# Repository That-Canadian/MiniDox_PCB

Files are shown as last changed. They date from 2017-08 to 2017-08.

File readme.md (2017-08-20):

MiniDox PCB
===

MiniDox

These are the KiCad PCB source files for the MiniDox keyboard, created by u/That-Canadian on reddit

For the KiCad footprints/schematic libraries used please go to my [KiCad Library repo](https://github.com/That-Canadian/KiCad_Libs)

For case files / drawings see [DotDash32's Github](https://github.com/dotdash32/Cases/tree/master/Minidox)

For firmware files see the [QMK Github](https://github.com/qmk/qmk_firmware)

Copyright © 2017 Chirstopher Poole <maple-computing@vault-tech.net>
This work is free. You can redistribute it and/or modify it under the
terms of the Do What The Fuck You Want To Public License, Version 2,
as published by Sam Hocevar. See the LICENSE file for more details.

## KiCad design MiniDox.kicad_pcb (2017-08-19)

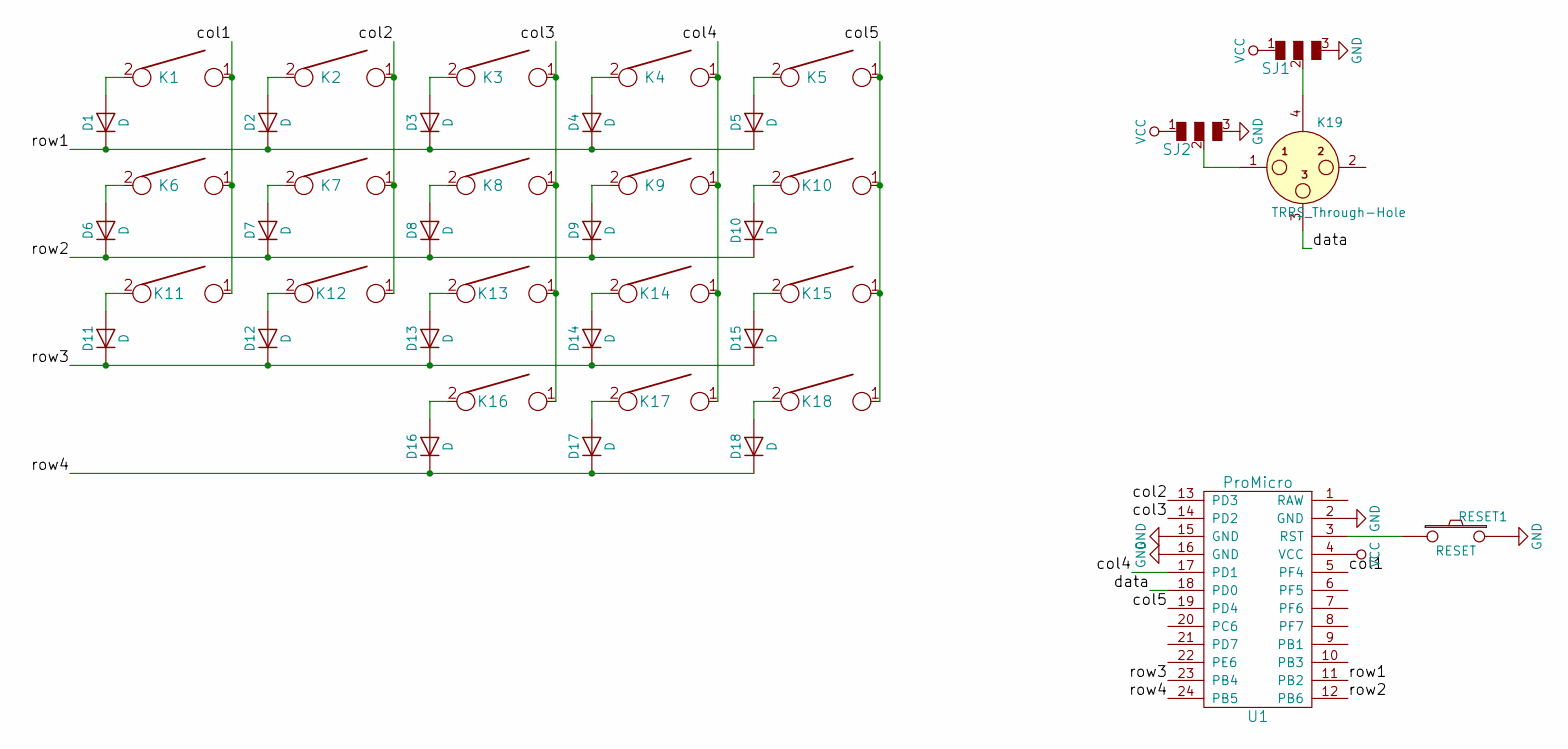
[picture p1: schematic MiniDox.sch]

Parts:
D1, D2, D3, D4, D5, D6, D7, D8, D9, D10, D11, D12, D13, D14, D15, D16, D17, D18: D; D_SOD123_axial-dual
K1, K2, K3, K4, K5, K6, K7, K8, K9, K10, K11, K12, K13, K14, K15, K16, K17: KEYSW; Mx_Alps_100-dualside
K18: KEYSW; Mx_Alps_175-dualside
K19: TRRS_Through-Hole; 4pin35mmAudio-dualsided
RESET1: RESET; SW_SPST_TL3342
SJ1, SJ2: SOLDER_JUMPER_3
U1: ProMicro; Pro_Micro

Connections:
/col1: K1.1, K6.1, K11.1, U1.5 (PF4)
/col2: K2.1, K7.1, K12.1, U1.13 (PD3)
/col3: K3.1, K8.1, K13.1, K16.1, U1.14 (PD2)
/col4: K4.1, K9.1, K14.1, K17.1, U1.17 (PD1)
/col5: K5.1, K10.1, K15.1, K18.1, U1.19 (PD4)
/data: K19.3, U1.18 (PD0)
/row1: D1.1 (K), D2.1 (K), D3.1 (K), D4.1 (K), D5.1 (K), U1.11 (PB2)
/row2: D6.1 (K), D7.1 (K), D8.1 (K), D9.1 (K), D10.1 (K), U1.12 (PB6)
/row3: D11.1 (K), D12.1 (K), D13.1 (K), D14.1 (K), D15.1 (K), U1.23 (PB4)
/row4: D16.1 (K), D17.1 (K), D18.1 (K), U1.24 (PB5)
GND: RESET1.2, SJ1.3, SJ2.3, U1.2 (GND), U1.15 (GND), U1.16 (GND); also elsewhere on the board
unnamed: D1.2 (A), K1.2
unnamed: D2.2 (A), K2.2
unnamed: D3.2 (A), K3.2
unnamed: D4.2 (A), K4.2
unnamed: D5.2 (A), K5.2
unnamed: D6.2 (A), K6.2
unnamed: D7.2 (A), K7.2
unnamed: D8.2 (A), K8.2
unnamed: D9.2 (A), K9.2
unnamed: D10.2 (A), K10.2
unnamed: D11.2 (A), K11.2
unnamed: D12.2 (A), K12.2
unnamed: D13.2 (A), K13.2
unnamed: D14.2 (A), K14.2
unnamed: D15.2 (A), K15.2
unnamed: D16.2 (A), K16.2
unnamed: D17.2 (A), K17.2
unnamed: D18.2 (A), K18.2
unnamed: K19.1, SJ2.2
unnamed: K19.4, SJ1.2
unnamed 32: RESET1.1, U1.3 (RST); also elsewhere on the board
VCC: SJ1.1, SJ2.1, U1.4 (VCC)

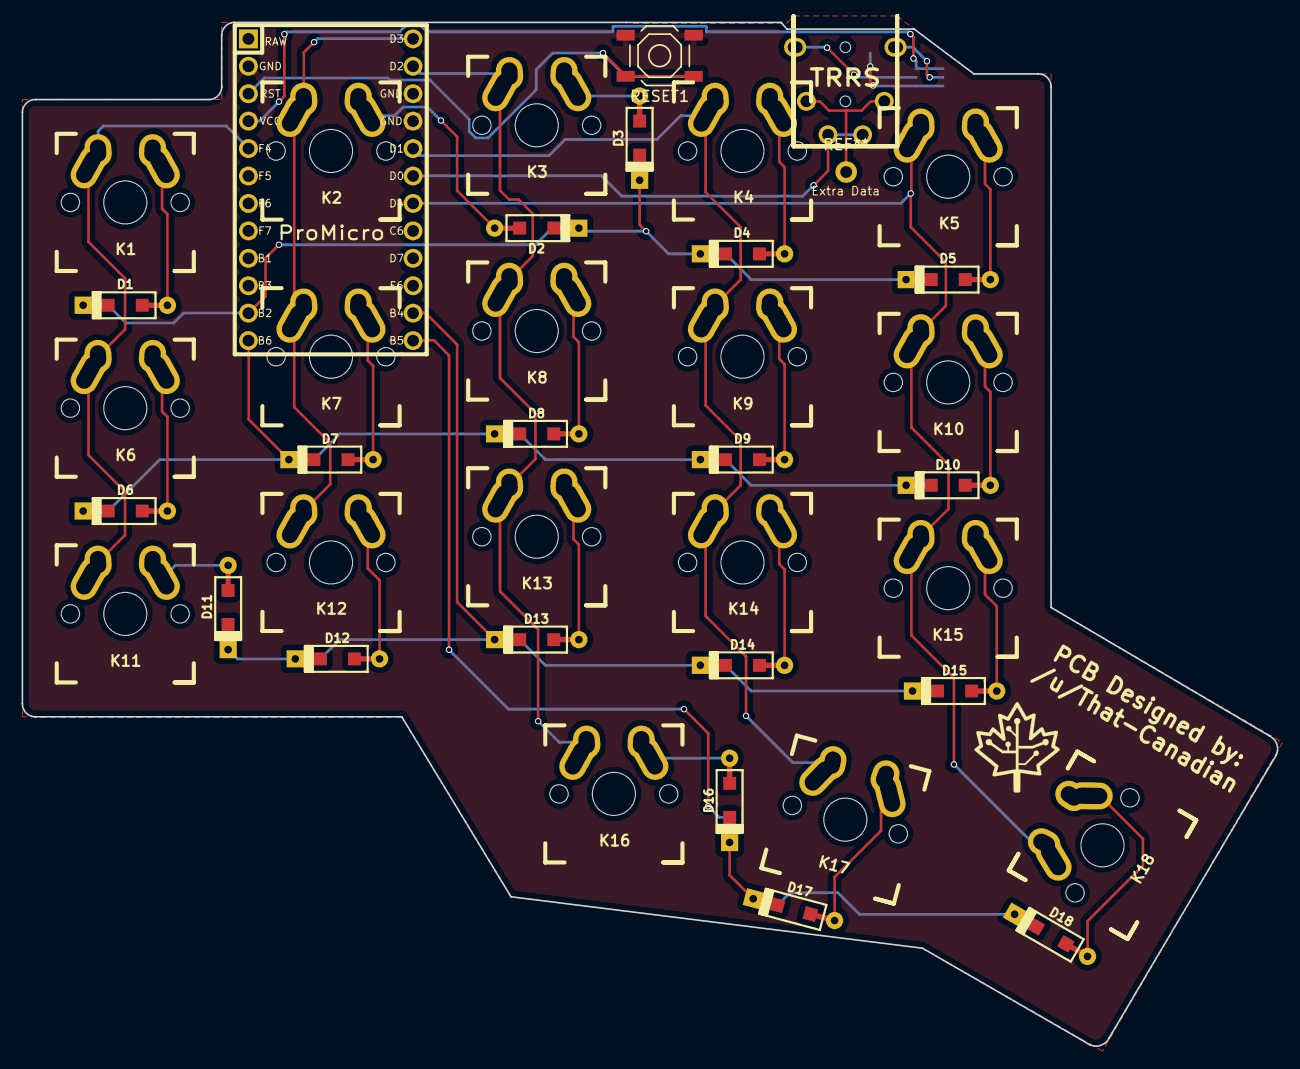
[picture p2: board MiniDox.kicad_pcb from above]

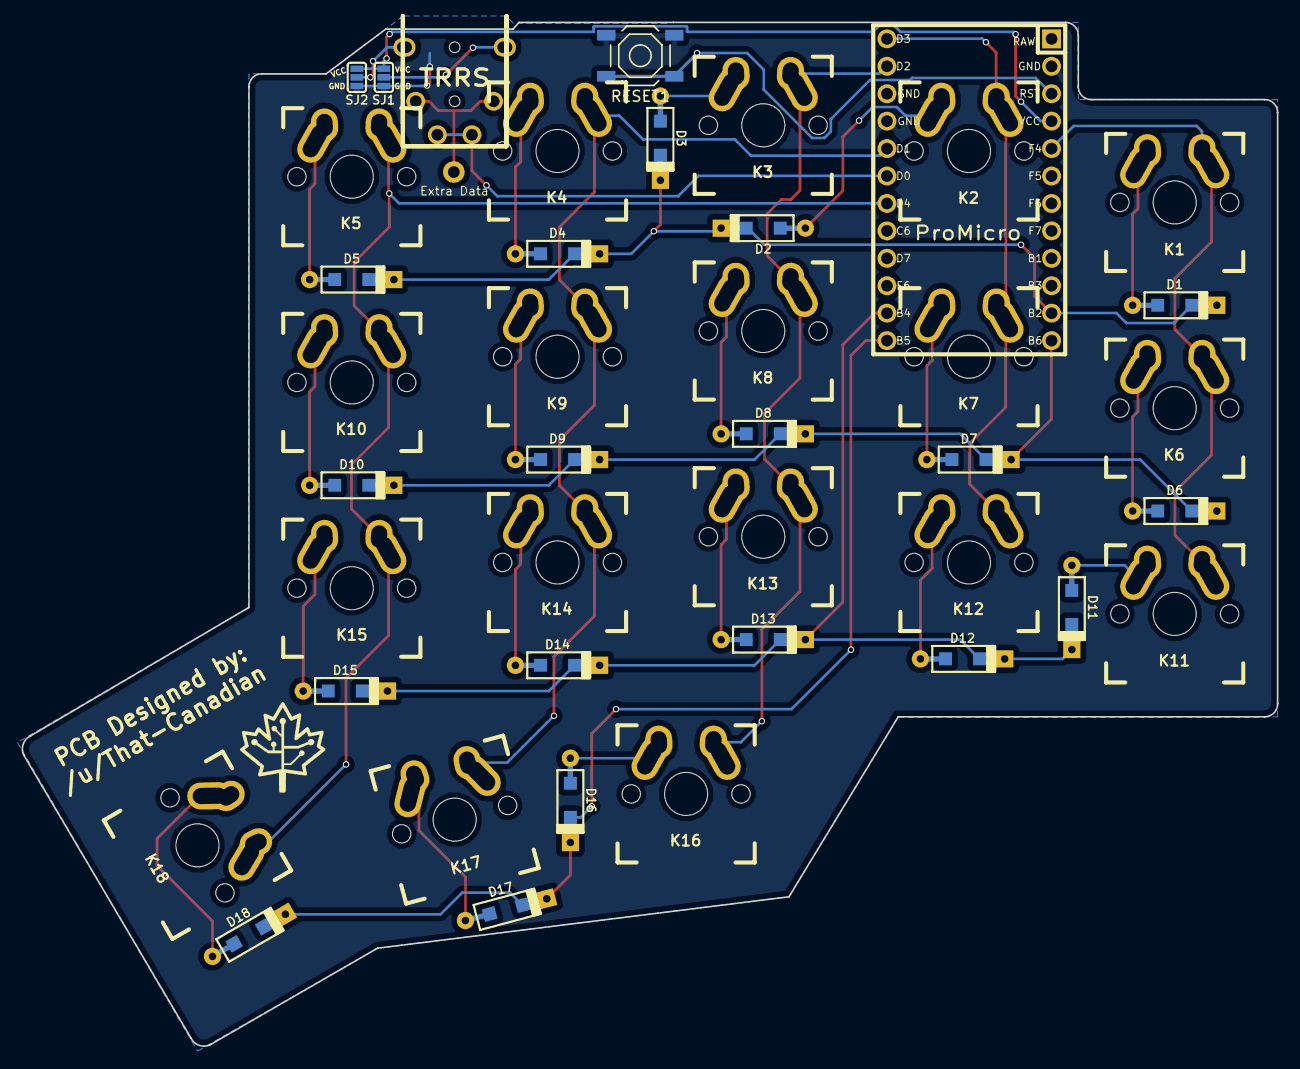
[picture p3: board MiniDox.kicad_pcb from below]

Board: 2 copper layers, 116.2 x 94.8 mm, 42 parts (21 on the bottom side), 33 nets.

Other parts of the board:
RESET1#2: RESET; SW_SPST_TL3342

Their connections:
GND: RESET1#2.2; also elsewhere on the board
unnamed 32: RESET1#2.1; also elsewhere on the board
